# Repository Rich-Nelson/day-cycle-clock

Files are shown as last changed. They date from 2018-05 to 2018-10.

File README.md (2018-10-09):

# day-cycle-clock

This repository contains the mechanical and electrical CAD for the Day Cycle Clock.  The code can be found in this repo https://github.com/Rich-Nelson/day-cycle-clock-code

Links to the build video and blog post coming soon.

## CAD
Contains the mechanical models.  In the root directoy there is a .STEP and .SLDASM of the full assembly

- **STL** Has all of the printable files for the project
- **SLDPRT** Contains the individual component models and sub assemblies
- **SLDDRW** Contaisn the 2-D dimensioned drawings for some of the fabricated components, mainly the wooden enclosure
- **Backlight Bracket** 3 versions of the backlight screen assembly were made depending on which you want to use.
    - **v1** Backlight assembly with through hole 5mm LEDs
    - **v2** Backlight assembly with SMD LEDs on perf board
    - **v3** Backlight assembly with custom PCB (found int he PCB folder)

## PCB
Contains the KiCAD PCB files and Gerbers.

**Note** I may need to update some customer libraries into this repo so that the KiCAD project will load properly on other computers.  But for now the gerbers are available to make your own boards.

## Graphics
Contains the vector outlines used for the 3 cutout layers.

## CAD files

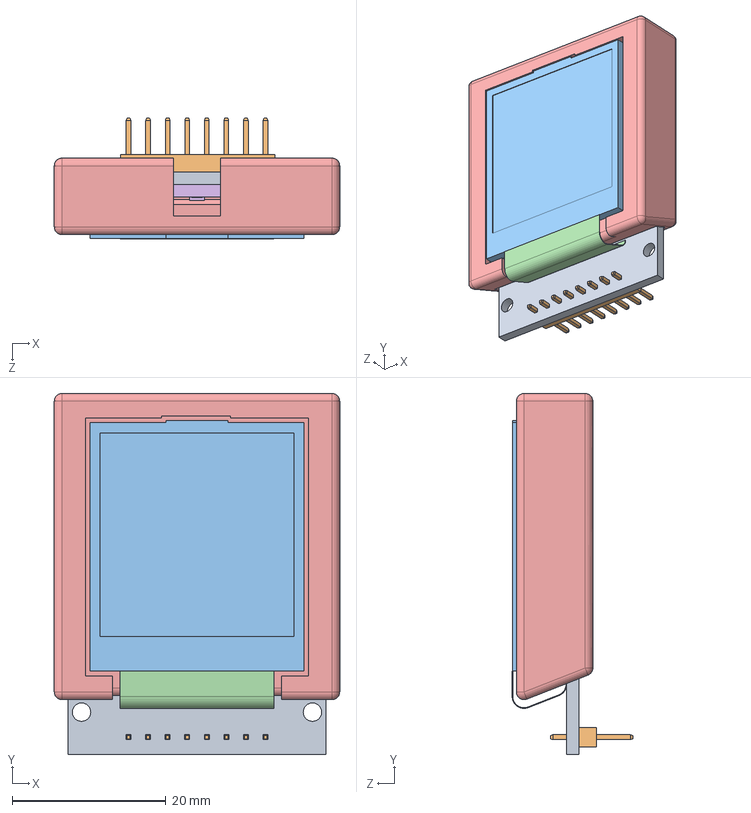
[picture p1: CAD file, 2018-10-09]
CAD/Backlight Bracket v3/Screen Assembly v3.SLDASM
37.1 x 46.9 x 15.7 mm
Screen v3 PCB
Straight Header - 1x8
TFT panel
Part3^Screen Assembly v3
Screen Bracket
PCB backlight

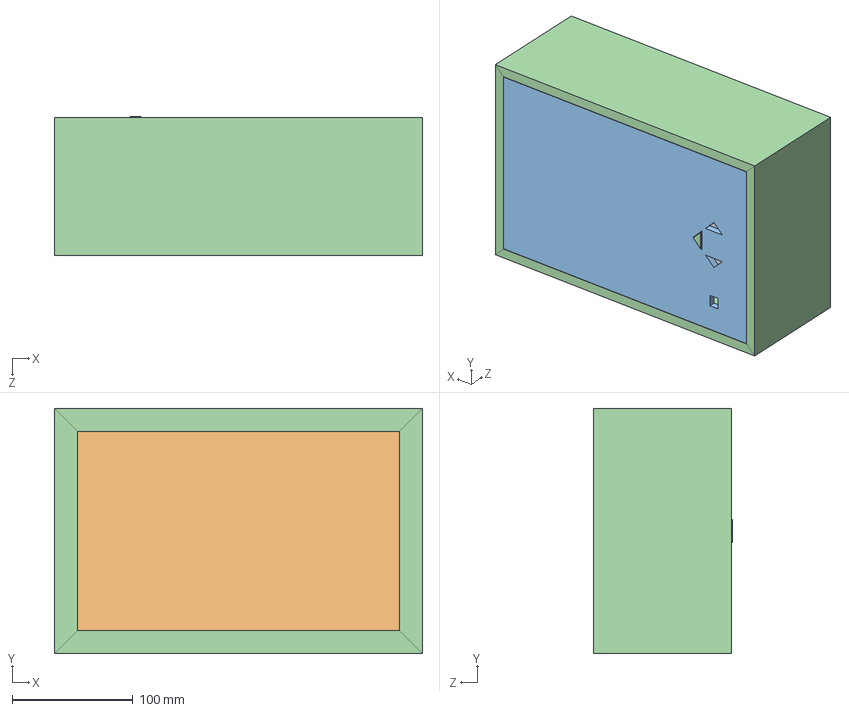
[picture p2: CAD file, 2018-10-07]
CAD/Light Box Assembly.SLDASM
304.8 x 203.2 x 115.4 mm
Paper Cutouts
Glass Panel
Screen v2 PCB
Straight Header - 1x8
Led Panel
TFT panel
Part3^Screen Assembly v2
Screen Bracket v2
Servo Body
Servo Horn
10mm MakerBeam
Wooden Enclosure
Beam to Screen Bracket
M3 Panhead Screw
M2.5 Panhead Screw x 6
Servo Mount
#6 Phillips Flathead Point .5in x 4
WS2812 Strip x 3
Frame - Back Panel

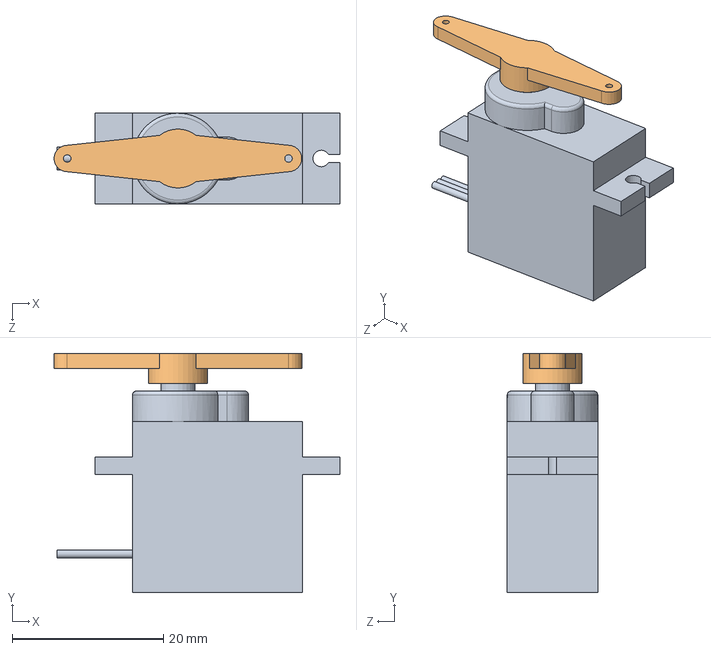
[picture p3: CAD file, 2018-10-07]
CAD/SLDPRT/Servo Assembly.SLDASM
37.9 x 31.7 x 12.0 mm
Servo Body
Servo Horn

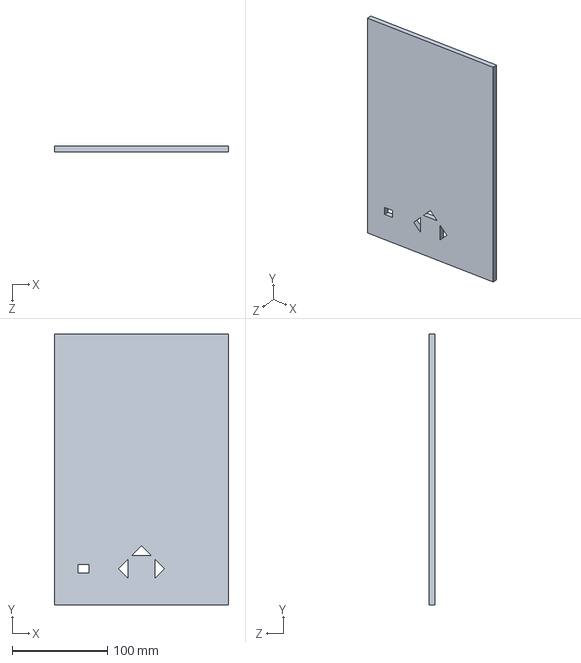
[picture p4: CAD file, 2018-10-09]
CAD/SLDPRT/Wooden Enclosure - Back Panel.SLDPRT
183.5 x 285.1 x 6.35 mm

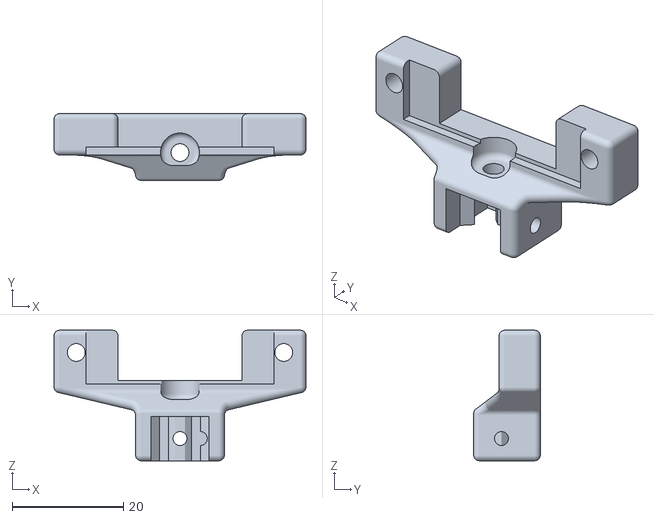
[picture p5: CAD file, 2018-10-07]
CAD/STL/Beam to Screen Bracket v3.STL
45.4 x 12.0 x 23.5

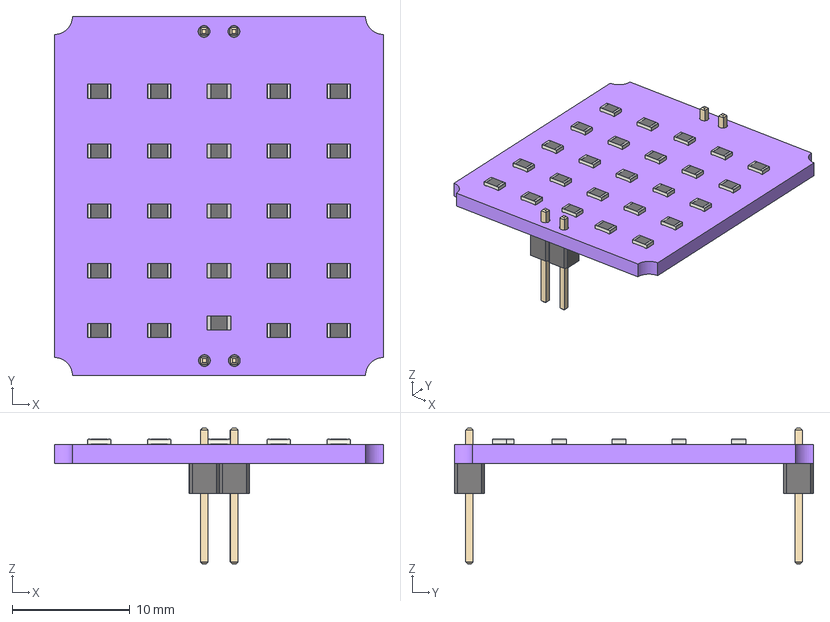
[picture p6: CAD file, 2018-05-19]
PCB/Backlight/Backlight/Backlight4.step
27.9 x 30.5 x 11.5 mm
Pcb
PinHeader_1x02_P254mm_Vertical_
PinHeader_1x02_P254mm_Vertical_001
R_0805_2012Metric_
R_0805_2012Metric_001
R_0805_2012Metric_002
R_0805_2012Metric_003
R_0805_2012Metric_004
R_0805_2012Metric_005
R_0805_2012Metric_006
R_0805_2012Metric_007
R_0805_2012Metric_008
R_0805_2012Metric_009
R_0805_2012Metric_010
R_0805_2012Metric_011
R_0805_2012Metric_012
R_0805_2012Metric_013
R_0805_2012Metric_014
R_0805_2012Metric_015
R_0805_2012Metric_016
R_0805_2012Metric_017
R_0805_2012Metric_018
R_0805_2012Metric_019
R_0805_2012Metric_020
R_0805_2012Metric_021
R_0805_2012Metric_022
R_0805_2012Metric_023
R_0805_2012Metric_024

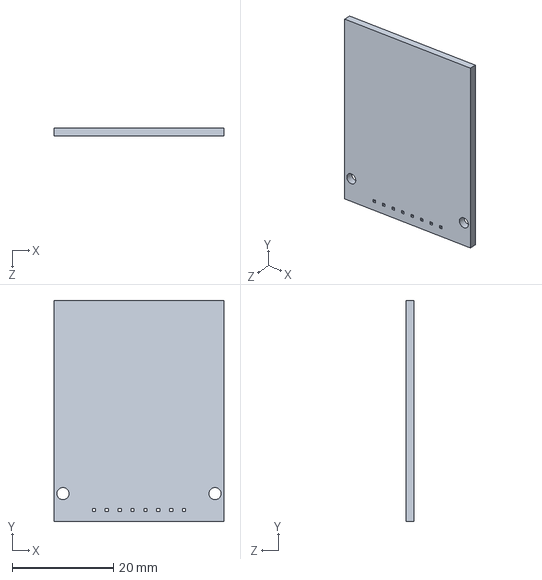
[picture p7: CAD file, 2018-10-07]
CAD/Backlight Bracket v3/Screen v3 PCB.SLDPRT
33.5 x 43.6 x 1.65 mm

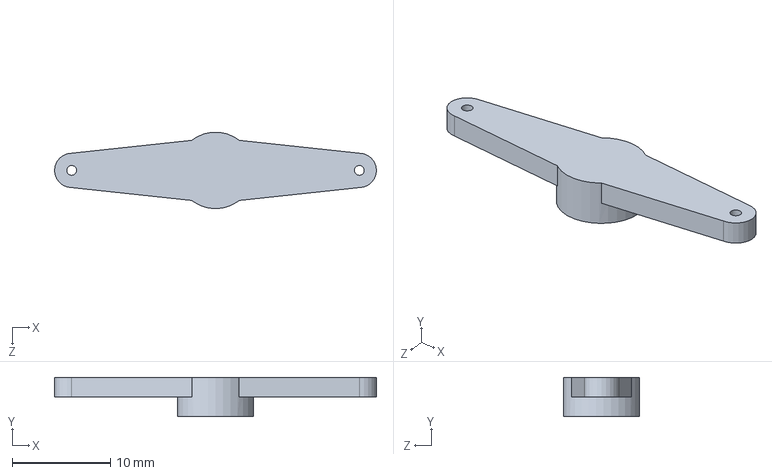
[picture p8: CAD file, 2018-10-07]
CAD/SLDPRT/Servo Horn.SLDPRT
32.8 x 4.00 x 7.78 mm

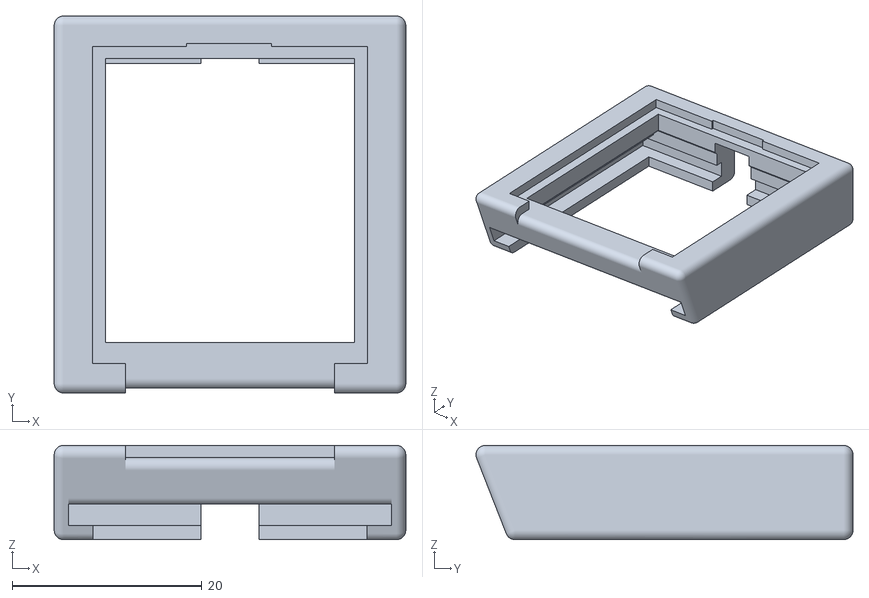
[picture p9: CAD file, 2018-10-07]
CAD/STL/Screen Bracket v3.STL
37.1 x 39.8 x 9.95

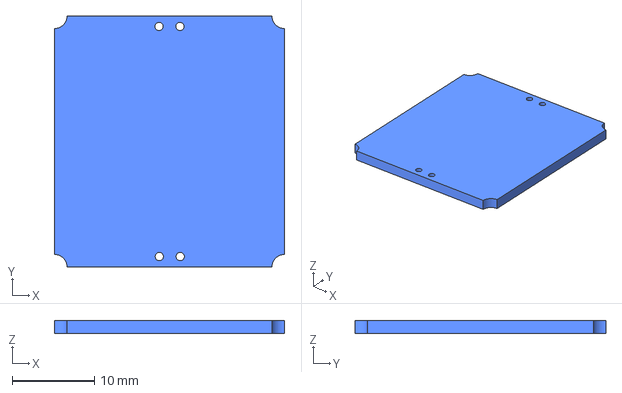
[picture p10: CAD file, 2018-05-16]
PCB/Backlight/Backlight/Backlight1.step
27.9 x 30.5 x 1.60 mm

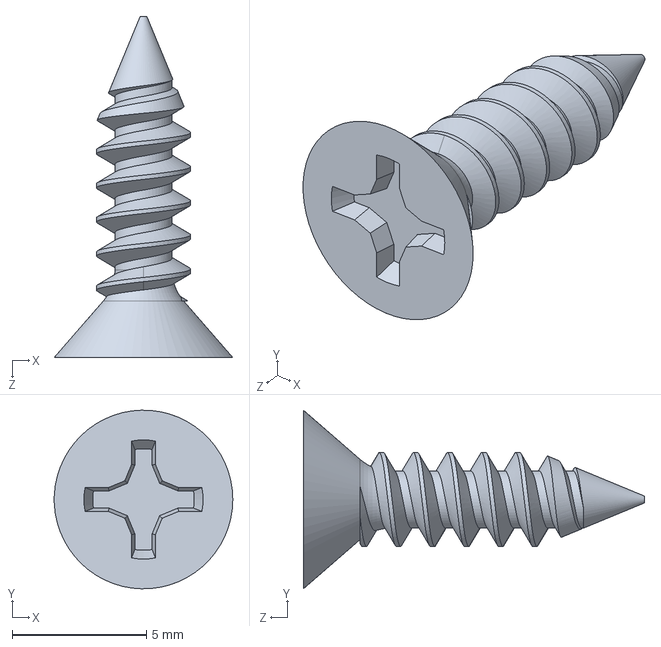
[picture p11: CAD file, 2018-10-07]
CAD/SLDPRT/#6 Phillips Flathead Point .5in.SLDPRT
6.65 x 6.65 x 12.7 mm

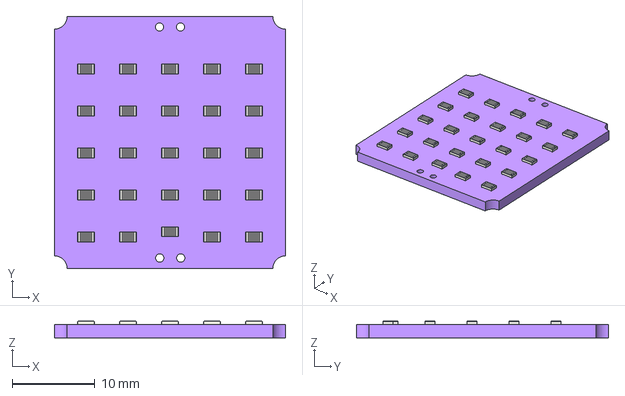
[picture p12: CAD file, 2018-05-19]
CAD/Backlight Bracket v3/PCB backlight.step
27.9 x 30.5 x 2.05 mm

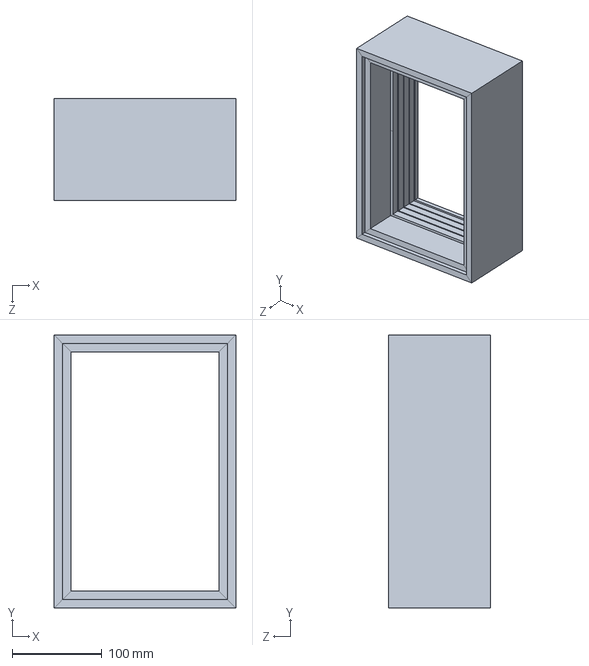
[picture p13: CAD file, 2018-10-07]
CAD/SLDPRT/Wooden Enclosure.SLDPRT
203.2 x 304.8 x 114.3 mm

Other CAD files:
Graphics/vector front buildings.dwg
Graphics/vector trees.dwg
CAD/Backlight Bracket v3/Screen Bracket.SLDPRT
Graphics/vector back buildings.dwg
PCB/Backlight/Backlight/Backlight2.step
CAD/Backlight Bracket v1/LED Panel Bracket v1.SLDPRT
CAD/Backlight Bracket v1/Led Panel.SLDPRT
CAD/Backlight Bracket v1/STL/LED Panel Bracket v1.STL
CAD/Backlight Bracket v1/Screen Backlight assembly.SLDASM
CAD/Backlight Bracket v1/Screen.SLDPRT
CAD/Backlight Bracket v2/STL/Screen Bracket v2 test.STL
CAD/Backlight Bracket v2/Screen Assembly v2.SLDASM
CAD/Backlight Bracket v2/Screen Bracket v2.SLDPRT
CAD/Backlight Bracket v2/Screen v2 PCB.SLDPRT
CAD/Backlight Bracket v3/PCB backlight.SLDPRT
CAD/Backlight Bracket v3/Straight Header - 1x8.SLDPRT
CAD/Backlight Bracket v3/TFT panel.SLDPRT
CAD/SLDDRW/Wooden Enclosure - Back Panel.SLDDRW
CAD/SLDDRW/Wooden Enclosure - Mitered Box Panel Drawing.SLDDRW
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

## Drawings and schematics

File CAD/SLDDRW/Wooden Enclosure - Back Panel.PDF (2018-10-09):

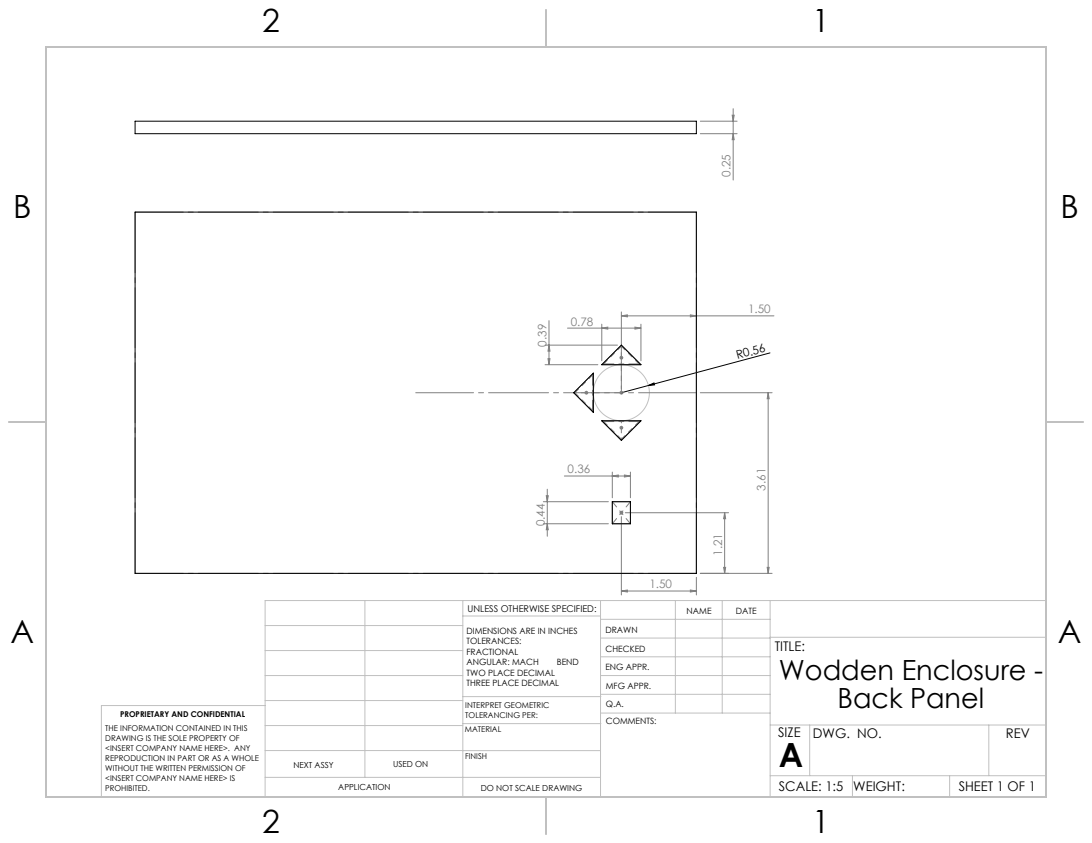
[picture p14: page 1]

UNLESS OTHERWISE SPECIFIED: | | NAME | DATE
DIMENSIONS ARE IN INCHES TOLERANCES: FRACTIONAL ANGULAR: MACH BEND TWO PLACE DECIMAL THREE PLACE DECIMAL | DRAWN

CHECKED | | | TITLE: Wodden Enclosure -Back Panel

ENG APPR.
MFG APPR.

INTERPRET GEOMETRIC TOLERANCING PER: | Q.A.
MATERIAL | | SIZE A | DWG. NO. | REV

PROPRIETARY AND CONFIDENTIAL
THE INFORMATION CONTAINED IN THIS
DRAWING IS THE SOLE PROPERTY OF
<INSERT COMPANY NAME HERE>. ANY
REPRODUCTION IN PART OR AS A WHOLE
WITHOUT THE WRITTEN PERMISSION OF
<INSERT COMPANY NAME HERE> IS
PROHIBITED.

NEXT ASSY | USED ON | FINISH

APPLICATION | DO NOT SCALE DRAWING | | SCALE: 1:5 | WEIGHT: | SHEET 1 OF 1

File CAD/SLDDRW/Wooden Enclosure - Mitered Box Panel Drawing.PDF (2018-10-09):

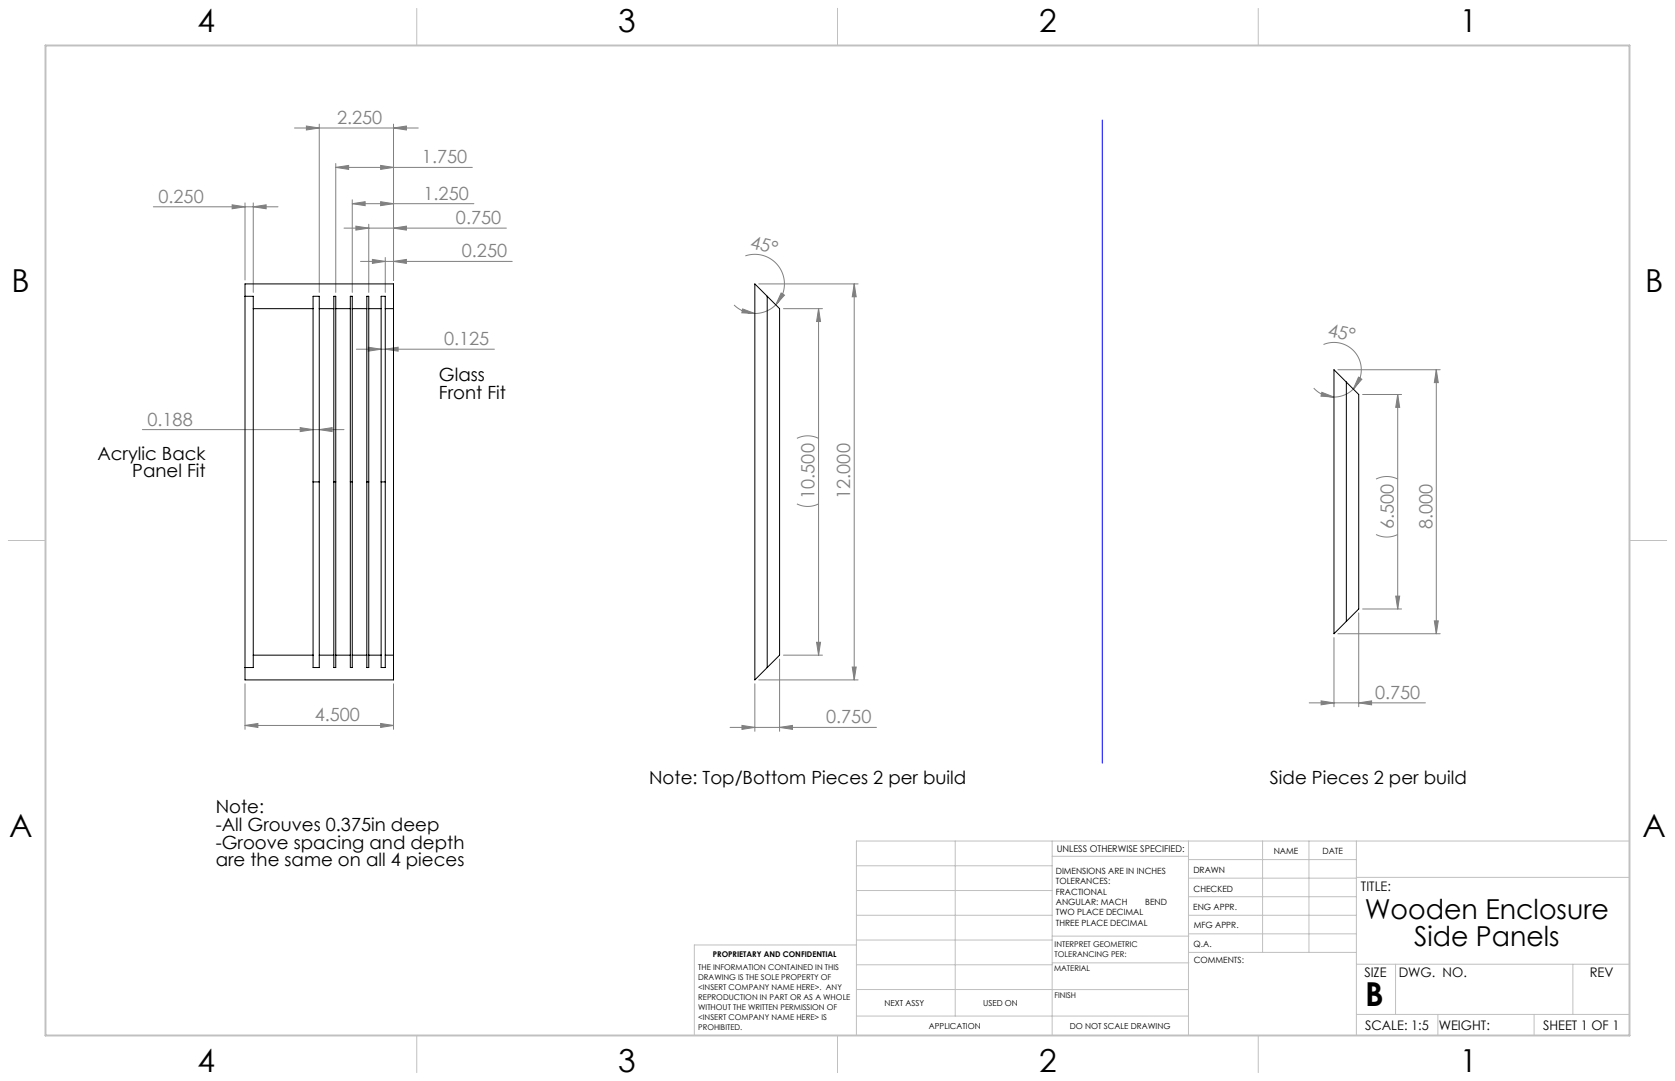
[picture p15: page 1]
Note: Top/Bottom Pieces 2 per build; Side Pieces 2 per build; Acrylic Back Panel Fit; Front Fit

Note:
-All Grouves 0.375in deep
-Groove spacing and depth
are the same on all 4 pieces

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

CHECKED | | | TITLE: Wooden Enclosure Side Panels

ENG APPR.
MFG APPR.

INTERPRET GEOMETRIC TOLERANCING PER: | Q.A.
MATERIAL | | SIZE B | DWG. NO. | REV

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

NEXT ASSY | USED ON | FINISH

APPLICATION | DO NOT SCALE DRAWING | | SCALE: 1:5 | WEIGHT: | SHEET 1 OF 1

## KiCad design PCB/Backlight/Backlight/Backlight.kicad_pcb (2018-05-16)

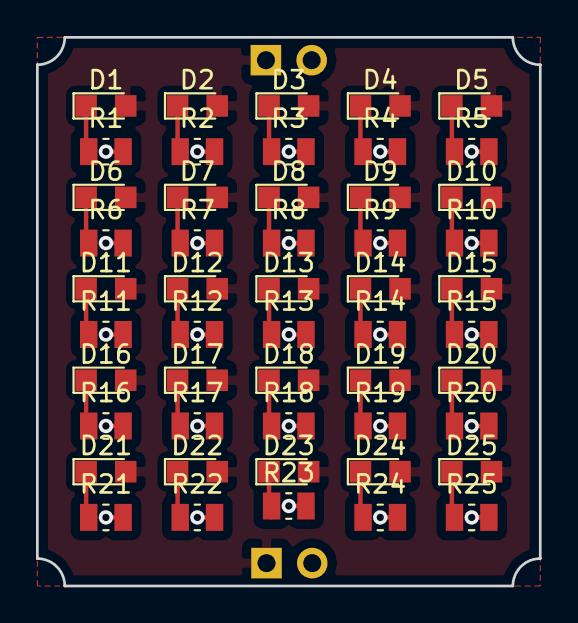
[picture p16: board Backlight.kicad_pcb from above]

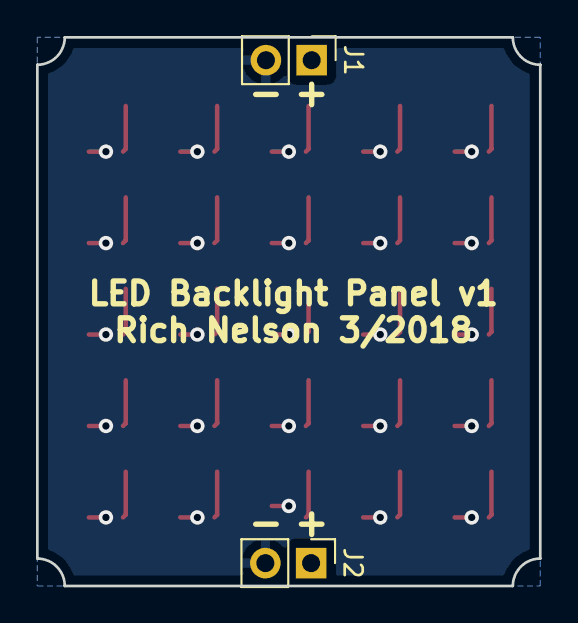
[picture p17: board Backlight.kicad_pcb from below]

Board: 2 copper layers, 27.9 x 30.5 mm, 52 parts (2 on the bottom side), 27 nets.

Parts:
D1, D2, D3, D4, D5, D6, D7, D8, D9, D10, D11, D12, D13, D14, D15, D16, D17, D18, D19, D20, D21, D22, D23, D24, D25: LED; LED_0805
J1, J2: Conn_01x02; PinHeader_1x02_P2.54mm_Vertical
R1, R2, R3, R4, R5, R6, R7, R8, R9, R10, R11, R12, R13, R14, R15, R16, R17, R18, R19, R20, R21, R22, R23, R24, R25: R; R_0805_2012Metric

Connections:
+5V: D1.2, D2.2, D3.2, D4.2, D5.2, D6.2, D7.2, D8.2, D9.2, D10.2, D11.2, D12.2, D13.2, D14.2, D15.2, D16.2, D17.2, D18.2, D19.2, D20.2, D21.2, D22.2, D23.2, D24.2, D25.2, J1.1, J2.1
GND: J1.2, J2.2, R1.2, R2.2, R3.2, R4.2, R5.2, R6.2, R7.2, R8.2, R9.2, R10.2, R11.2, R12.2, R13.2, R14.2, R15.2, R16.2, R17.2, R18.2, R19.2, R20.2, R21.2, R22.2, R23.2, R24.2, R25.2
unnamed: D1.1, R1.1
unnamed: D2.1, R2.1
unnamed: D3.1, R3.1
unnamed: D4.1, R4.1
unnamed: D5.1, R5.1
unnamed: D6.1, R6.1
unnamed: D7.1, R7.1
unnamed: D8.1, R8.1
unnamed: D9.1, R9.1
unnamed: D10.1, R10.1
unnamed: D11.1, R11.1
unnamed: D12.1, R12.1
unnamed: D13.1, R13.1
unnamed: D14.1, R14.1
unnamed: D15.1, R15.1
unnamed: D16.1, R16.1
unnamed: D17.1, R17.1
unnamed: D18.1, R18.1
unnamed: D19.1, R19.1
unnamed: D20.1, R20.1
unnamed: D21.1, R21.1
unnamed: D22.1, R22.1
unnamed: D23.1, R23.1
unnamed: D24.1, R24.1
unnamed: D25.1, R25.1

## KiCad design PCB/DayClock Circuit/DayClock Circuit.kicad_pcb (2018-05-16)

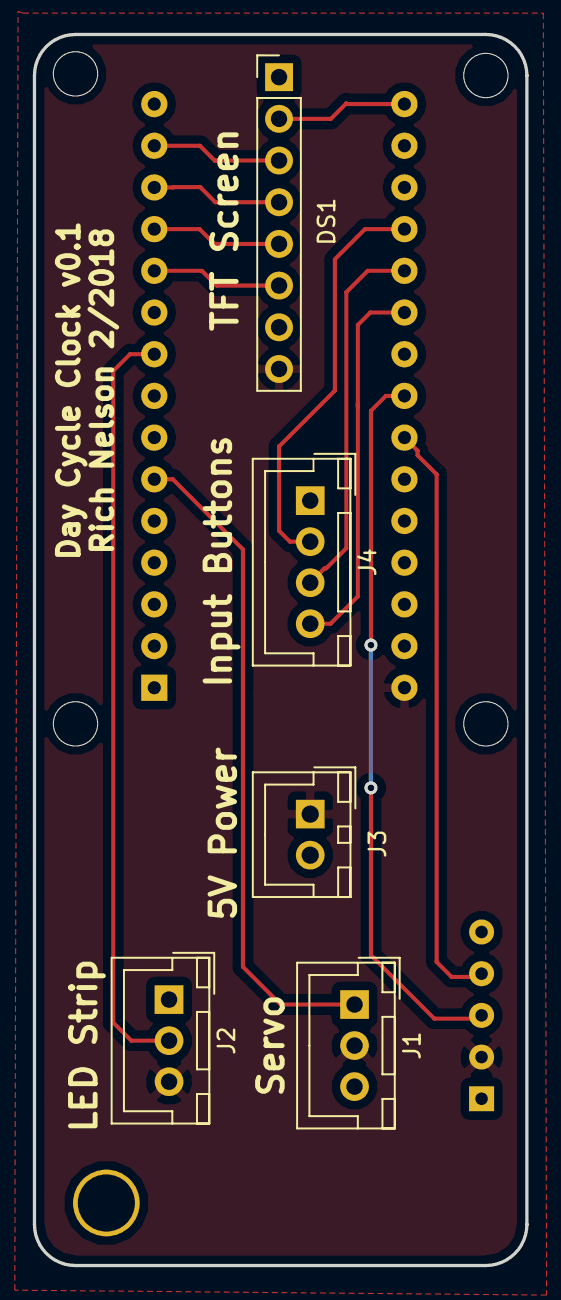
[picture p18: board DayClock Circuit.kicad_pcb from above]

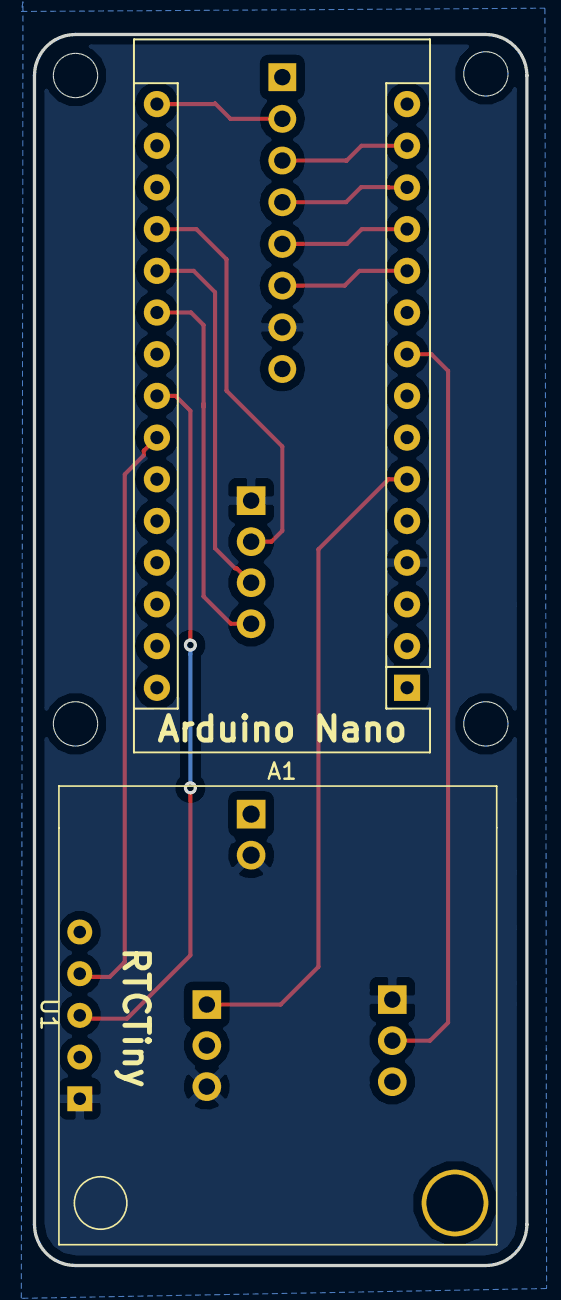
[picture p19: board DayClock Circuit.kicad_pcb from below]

Board: 2 copper layers, 30.0 x 75.0 mm, 7 parts (2 on the bottom side), 14 nets.

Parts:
A1: Arduino_Nano_v3.x; Arduino_Nano
DS1: TFT-Screen-1.44-SPI-128*128; Socket_Strip_Straight_1x08_Pitch2.54mm
J1: Servo Conn_01x03_Male; JST_XH_B03B-XH-A_03x2.50mm_Straight
J2: LED Strip Conn_01x03_Male; JST_XH_B03B-XH-A_03x2.50mm_Straight
J3: 5V Power Connector; JST_XH_B02B-XH-A_02x2.50mm_Straight
J4: Input Button Connector; JST_XH_B04B-XH-A_04x2.50mm_Straight
U1: Tiny_RTC_DS1307; TinyRTC-one-mounting-hole

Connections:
+5V: A1.30, DS1.8, J1.2, J2.3, J3.1, U1.2
/BTN_1: A1.21, J4.4
/BTN_2: A1.20, J4.3
/BTN_3: A1.19, J4.2
/LED_DATA: A1.9, J2.2
/RTC_SCL: A1.24, U1.4
/RTC_SDA: A1.23, U1.3
/SVO_DATA: A1.6, J1.1
/TFT_A0: A1.13, DS1.4
/TFT_CS: A1.11, DS1.6
/TFT_RST: A1.12, DS1.5
/TFT_SCK: A1.16, DS1.2
/TFT_SDA: A1.14, DS1.3
GND: A1.4, DS1.7, J1.3, J2.1, J3.2, J4.1, U1.1

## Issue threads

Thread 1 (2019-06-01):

Alternative diffusing method.

st2000, 2019-06-01:
Not an issue, but I don't think github has a project "suggestion box" feature.
I really like this build and the results look great.  Currently, I am trying to back light an old stain glass window with an addressable LED array in a bid to make wall art.  I too do not want to make this wall art overly thick.  I am still experimenting, but plan to use photography flash diffusing cloth.  It is inexpensive, readily available in large sizes and very light.  I may use 1 layer or wrap it around a wooden frame to form 2 layers with a gap in the middle.

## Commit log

2018-05-16 Initial commit, day-cycle-clock rev 1
    [#6 Phillips Flathead Point .5in.SLDPRT, 100056.SLDPRT, 10mm MAkerBeam.SLDPRT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]
2018-05-19 Added support for altrnate TFT screen. there sems to be a huge numbr of 1.44 TFT screens on the marked with minor differences in dimensions and protocals.
    [Backlight2.FCStd, Backlight4.FCStd, Backlight4.step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]
2018-10-07 Cleaned up directory
    [#6 Phillips Flathead Point .5in.SLDPRT, 100056.SLDPRT, 10mm MAkerBeam.SLDPRT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]
2018-10-09 Added README and added additional drawings
    [2812 60 per meter parasolid.x_t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]
